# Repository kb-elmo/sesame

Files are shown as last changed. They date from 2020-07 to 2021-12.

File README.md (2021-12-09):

# Sesame

[][cc-by-nc-sa]
<a href="https://ko-fi.com/kb_elmo">kofibadge</a>

### Alice like ergo keyboard using only THT parts



### Partslist
 |Count|Part|Reference|LCSC Part #|
 |-|-|-|-|
 |1|ATmega32A 40 pin DIP (32L works too)|U1|C12703|
 |1|40 pin DIP socket (optional but highly recommended)|U1|C2332|
 |1|USB4085-GF-A USB Type-C socket|USB1|
 |1|500 mA polyfuse|F1|C207122|
 |2|6mm momentary push buttons|Boot,Reset|C620202|
 |1|16 MHz quartz crystal|XTAL1|C16212|
 |1|4.7 uF electrolytic capacitor|C1|C47879|
 |2|100 nF ceramic disk capacitor|C2,C3|C254092|
 |2|22 pF ceramic disk capacitor|C4,C5|C254096|
 |1|1.5 kΩ resistor|R1|C58620|
 |2|68 Ω resistor|R2,R3|C714279|
 |2|5.1 kΩ resistor|R4,R5|C714593|
 |1|10 kΩ resistor|R6|C119347|
 |2|3.6 V zener diode (DO-35 BZX55C3V6)|D1,D2|C2508|
 |66|universal switching diode (DO-35 1N4148)|D3-D68|C14516|
 
 The USB port can be found here:  
https://www.digikey.com/en/products/detail/gct/USB4085-GF-A/9859733

-----




This work is licensed under a
[Creative Commons Attribution-NonCommercial-ShareAlike 4.0 International License][cc-by-nc-sa].

[][cc-by-nc-sa]

[cc-by-nc-sa]: http://creativecommons.org/licenses/by-nc-sa/4.0/
[cc-by-nc-sa-image]: https://licensebuttons.net/l/by-nc-sa/4.0/88x31.png
[cc-by-nc-sa-shield]: https://img.shields.io/badge/License-CC%20BY--NC--SA%204.0-lightgrey.svg

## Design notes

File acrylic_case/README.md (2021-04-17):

# Sesame Acrylic Case

[][cc-by-nc-sa]

### Acrylic layer case for the Sesame Ergo



### To build the case you need:
|Count|Part|
|-|-|
|1|[Top plate](layer-top.dxf)|
|3|[Top frame](layer-frame-top.dxf)|
|1|[Switchplate](layer-plate.dxf)|
|2|[Bottom frame with USB cutout](layer-frame-bottom-usb.dxf)|
|2|[Bottom frame without USB cutout](layer-frame-bottom.dxf)|
|1|[Bottom plate](layer-bottom.dxf)|
|3|[Big feet plate](layer-feet-big.dxf)|
|2|[Small feet plate](layer-feet-small.dxf)|
|1|[Bottom feet plate](layer-feet-bottom.dxf)|

The case is designed to be built out of 2mm acrylic sheets with the switchplate in 1.5mm.  
For screwing everything together m2 standoffs and screws are used.

You can change the appearance of the board slightly by using more or less top frame plates.  
If you use 2 plates the keycaps will roughly sit at the same height of the case.  
With 3 plates the bottom of the keycaps sits slightly lower (which imho looks a bit better).  
The board in the picture has 2 top frame plates installed.

The case angle can be adjusted by the number of feet plates you attach to it.<br>
With six plates you will get roughly six degrees of typing angle.

---

This work is licensed under a
[Creative Commons Attribution-NonCommercial-ShareAlike 4.0 International License][cc-by-nc-sa].

[][cc-by-nc-sa]

[cc-by-nc-sa]: http://creativecommons.org/licenses/by-nc-sa/4.0/
[cc-by-nc-sa-image]: https://licensebuttons.net/l/by-nc-sa/4.0/88x31.png
[cc-by-nc-sa-shield]: https://img.shields.io/badge/License-CC%20BY--NC--SA%204.0-lightgrey.svg

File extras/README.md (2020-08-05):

# Extras for the Sesame







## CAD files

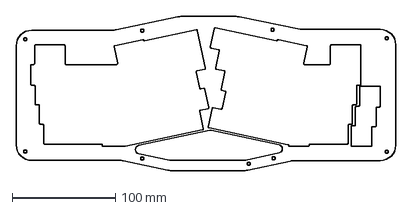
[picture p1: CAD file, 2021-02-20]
acrylic_case/layer-frame-top.dxf
368.4 x 149.6 mm

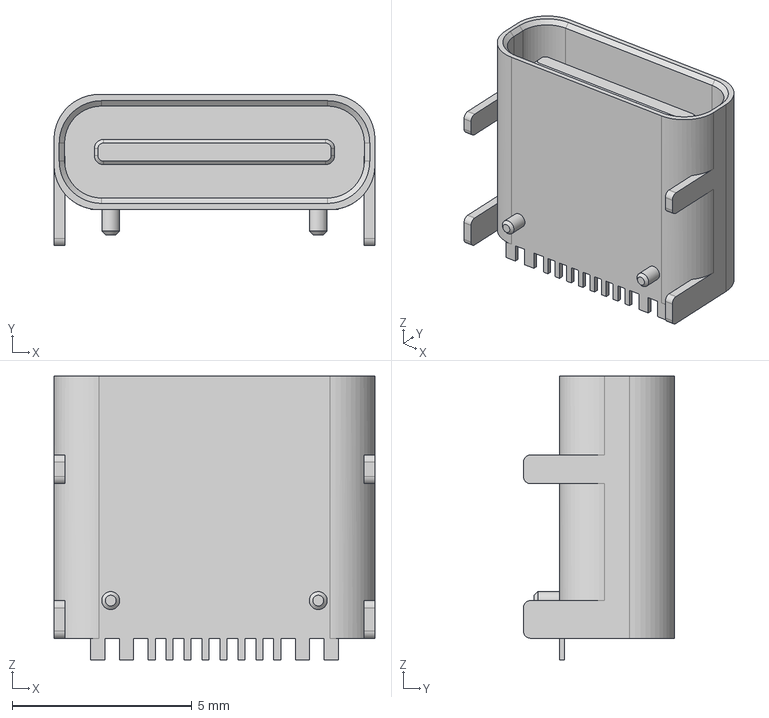
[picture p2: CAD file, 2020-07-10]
custom_parts/HRO TYPE-C-31-M-12.step
8.94 x 4.21 x 7.90 mm

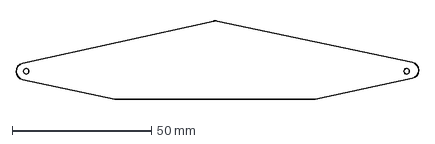
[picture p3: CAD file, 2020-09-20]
extras/case_parts/window.dxf
144.5 x 28.2 mm

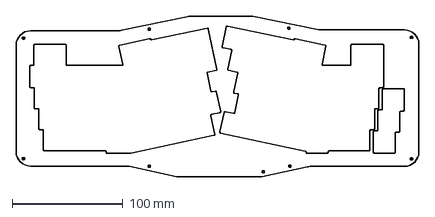
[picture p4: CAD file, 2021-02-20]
acrylic_case/layer-top.dxf
364.4 x 145.6 mm

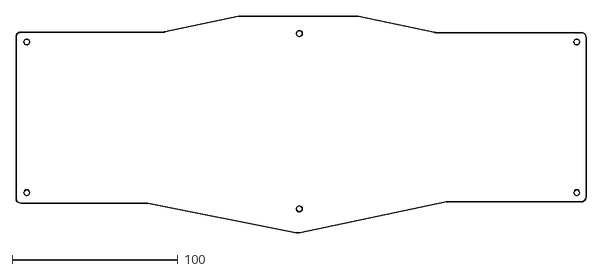
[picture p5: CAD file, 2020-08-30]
extras/case_parts/backplate-foam.dxf
344.4 x 131.0

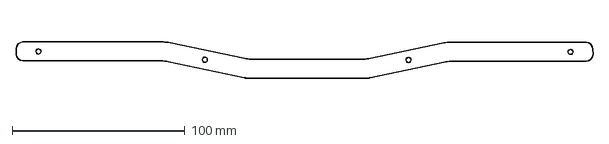
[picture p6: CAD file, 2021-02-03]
acrylic_case/layer-feet-small.dxf
334.3 x 20.9 mm

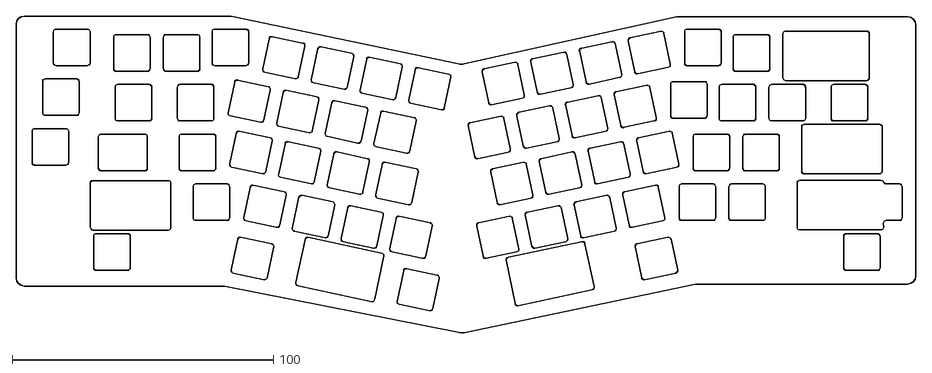
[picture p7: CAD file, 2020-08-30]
extras/case_parts/switchplate-foam.dxf
344.4 x 121.3

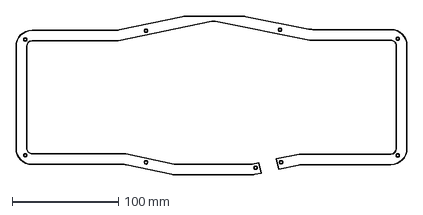
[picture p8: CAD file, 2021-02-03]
acrylic_case/layer-frame-bottom-usb.dxf
368.4 x 149.6 mm

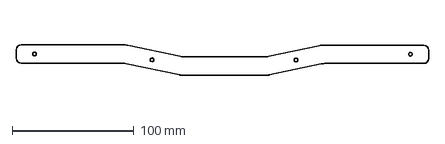
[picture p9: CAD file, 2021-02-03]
acrylic_case/layer-feet-big.dxf
338.3 x 24.9 mm

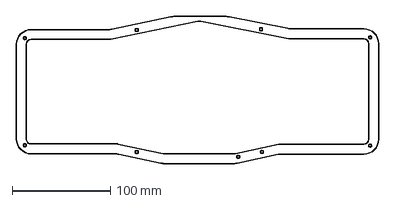
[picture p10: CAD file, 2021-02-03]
acrylic_case/layer-frame-bottom.dxf
368.4 x 149.6 mm

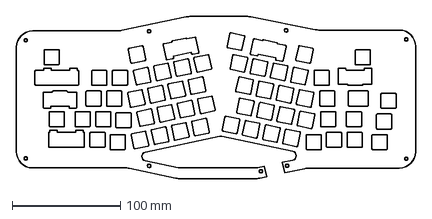
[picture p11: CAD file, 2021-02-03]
acrylic_case/layer-plate.dxf
368.4 x 149.6 mm

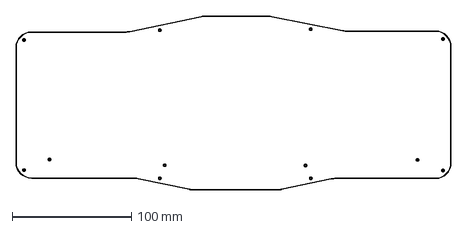
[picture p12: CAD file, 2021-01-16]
acrylic_case/layer-bottom.dxf
364.4 x 145.6 mm

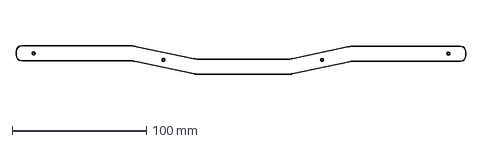
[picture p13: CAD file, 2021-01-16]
acrylic_case/layer-feet-bottom.dxf
334.3 x 20.9 mm

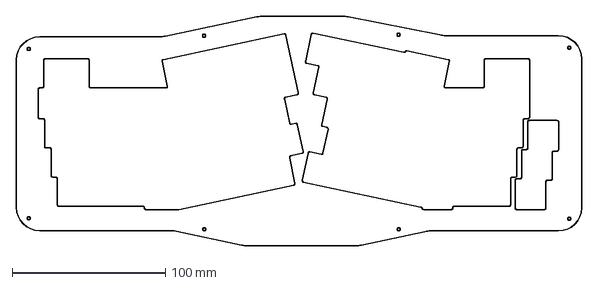
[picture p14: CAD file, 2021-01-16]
acrylic_case/sheet-top.dxf
368.4 x 149.6 mm

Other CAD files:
acrylic_case/sheet-frame-bottom-usb.dxf
acrylic_case/sheet-frame-bottom.dxf
acrylic_case/sheet-frame-top.dxf
acrylic_case/sheet-bottom.dxf

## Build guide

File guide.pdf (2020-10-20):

## Sesame Ergo build guide

Very quick and dirty build guide.
If you need further help DM me on Reddit (u/_vastrox_) or on Discord (elmo#0101).

Parts included:
1 | Sesame PCB
1 | Sesame Backplate (Logo on the back)
1 | Sesame FR4 switchplate
1 | Acrylic cover window
1 | Backplate foam
8 | M2 screws
8 | M2 nuts
6 | M2x4 standoffs for the backplate
2 | M2x10 standoffs for the acrylic window
1 | ATmega32A controller
1 | 40 pin DIP socket (optional but highly recommended)
1 | USB Type-C socket (USB4085-GF-A)
1 | 500 mA polyfuse
2 | 6mm momentary push buttons
1 | 16 MHz quartz crystal
1 | 4.7 uF electrolytic capacitor
2 | 100 nF ceramic disk capacitor
2 | 22 pF ceramic disk capacitor
1 | 10 kΩ resistor
1 | 1.5 kΩ resistor
2 | 68 Ω resistor
2 | 5.1 kΩ resistor
2 | 3.6 V zener diode (DO-35 BZX55C3V6)
80 | universal switching diode (DO-35 1N4148)

You only need 66 of the switching diodes for the board. The rest are replacements in case one gets damaged during soldering.

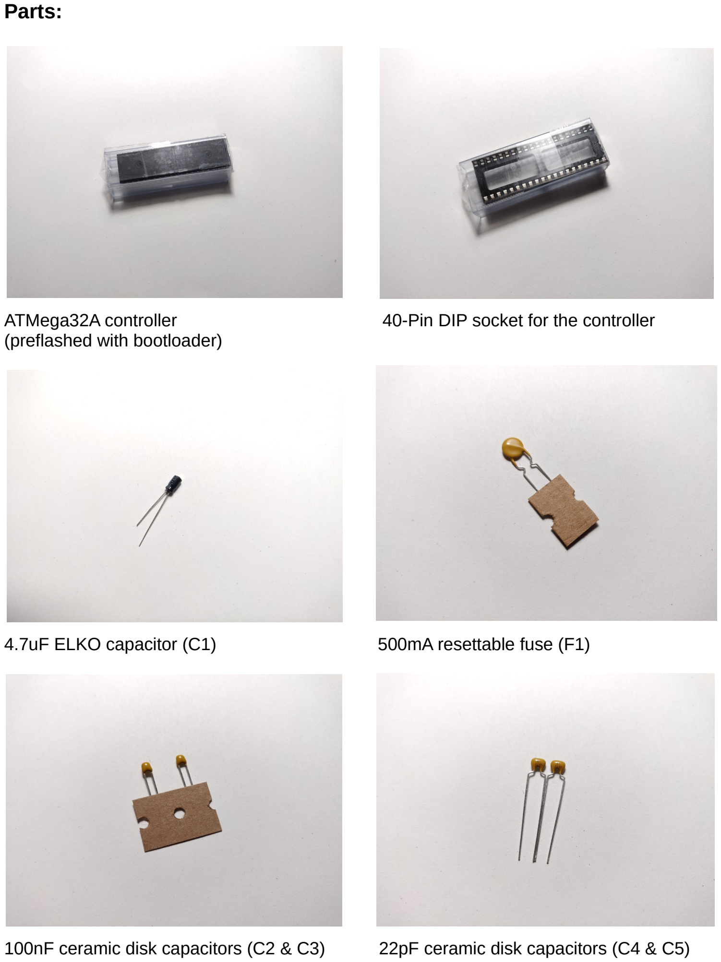
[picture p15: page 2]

Parts:

ATMega32A controller | 40-Pin DIP socket for the controller
(preflashed with bootloader)
4.7uF ELKO capacitor (C1) | 500mA resettable fuse (F1)
100nF ceramic disk capacitors (C2 & C3) | 22pF ceramic disk capacitors (C4 & C5)

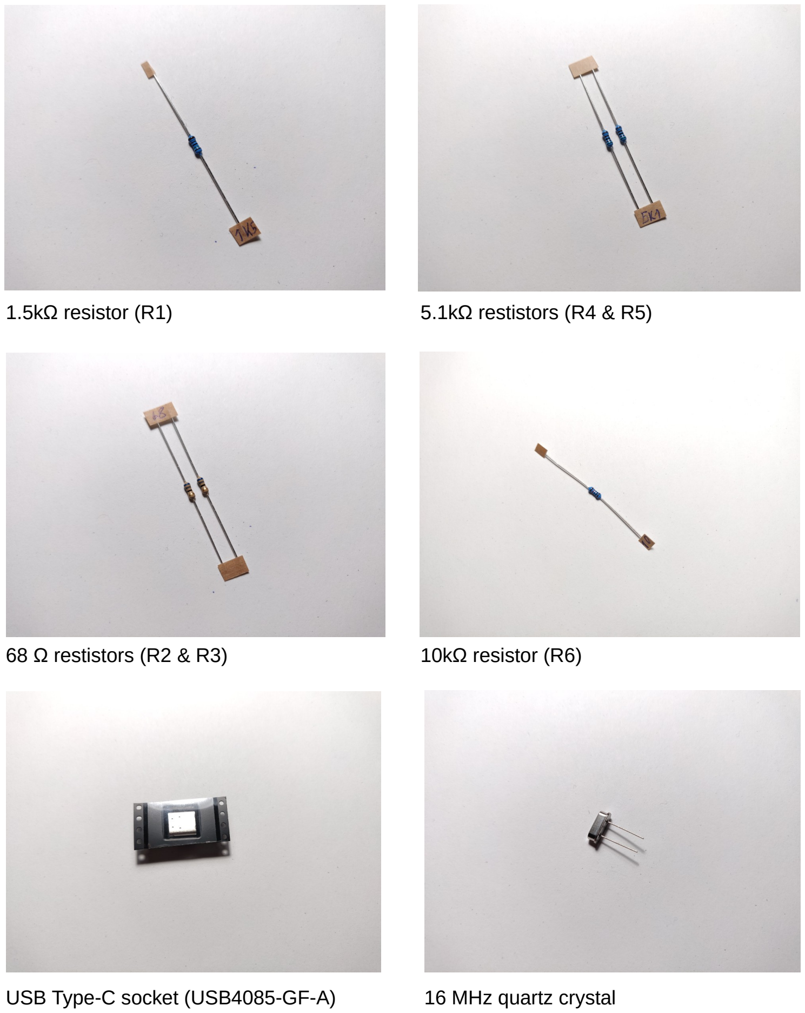
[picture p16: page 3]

1.5kΩ resistor (R1) | 5.1kΩ restistors (R4 & R5)
68 Ω restistors (R2 & R3) | 10kΩ resistor (R6)
USB Type-C socket (USB4085-GF-A) | 16 MHz quartz crystal

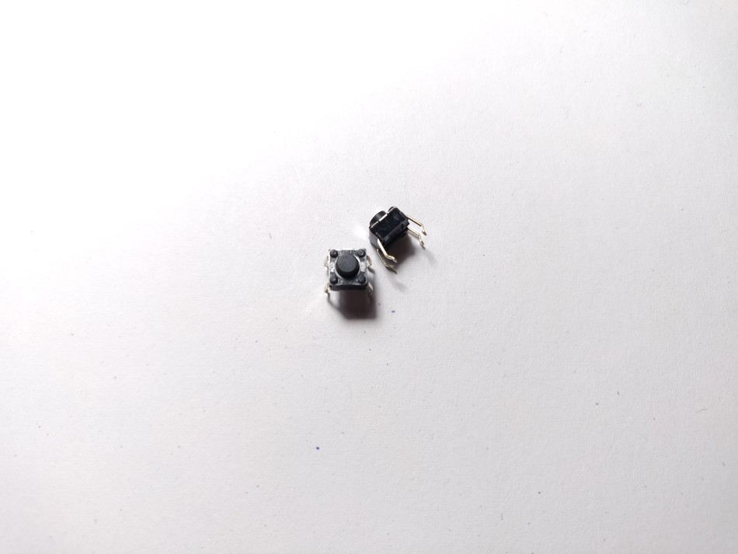
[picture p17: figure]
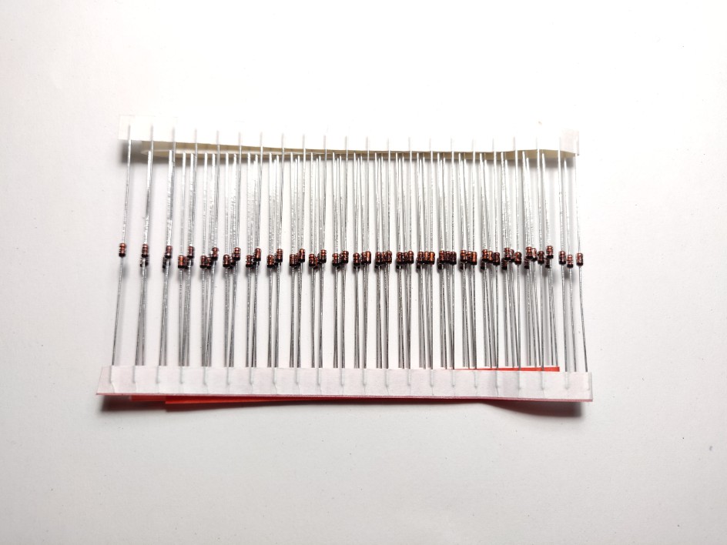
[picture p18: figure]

6mm pushbuttons (reset & boot) | universal switching diodes (80x)

Building the PCB:

1. Start with the USB-C port as this is the most complicated part to solder in this kit.
Put in the port and secure it in place with some electrical tape.
Next put on some flux over the pins on the bottom of the PCB.
Melt some solder on the tip of your iron and carefully drag the iron tip with the solder over the pins. The solder should stick to the pins without creating any bridges between them if you used enough flux.
If you don‘t get it right on the first try remove the solder with some whick and try it again. It‘s important that there are absolutely no shorts between the contacts. Otherwise the board will not work.
2. Next should be the controller socket. Put it in with the cutout nose like it‘s shown on the PCB silkscreen. Hold it in place with some electrical tape on top of the board. Solder every second pin on the board to prevent overheating the plastic. Then do the rest of the pins.
3. Solder in the quartz crystal into it‘s spot next to the controller (XTAL1). Polarity doesn‘t matter here. Do not pull hard on the parts legs as this can damage the part.

### 4. Solder in the capacitors. The values are as follows:

- C1 (ELKO! Watch the polarity! white side = negative) = 4.7uF
- C2 & C3 (next to the controller socket) = 100nF
- C4 & C5 (left and right of the crystal) = 22pF

### 5. Next up are the two 3.6V Zener diodes. They go into the spots D1 and D2. Watch the

polarity! The white line on the silkscreen has to match with the black or white line on the diode.
These are special diodes! They can not be exchanged with the standard switching diodes! Make sure that you are using the correct ones.
They are labeled 3V6 on their side. The switching diodes don‘t have that label.

### 6. Now come the resistors. Their values are as follows:

- R1 = 1.5kΩ
- R2 & R3 = 68Ω
- R4 & R5 = 5.1kΩ
- R6 (next to the buttons) = 10kΩ

### 7. Solder in the rest of the parts:

- the 500mA polyfuse (spot F1)
- the boot and reset pushbuttons
- the contacts labeled „AVR“ above the controller are left empty

### 8. Finish the board by soldering in all 66 diodes. Watch the polarity (white stripe)!

9. Lastly put the controller into the socket. Make sure that the indentation on the controller matches with the indentation in the socket! If you put it in the wrong way round it can destroy the controller.
Press it down firmly so that it sits flush with the socket. Take care to not bend any legs.

Assembly guide:

1. Start with the standoffs for the backplate.
Put in the standoffs (M2x4) from the bottom through the PCB and screw them in place with the M2 nuts.
2. Screw in the standoffs for the acrylic window.
Put the standoffs (M2x10) in from the front of the PCB and screw them in place with the M2 nuts on the back side.

### 3. Next put the included foam on the back of the PCB. The holes should align with the

standoffs. If it doesn‘t fit turn it around. It only fits on one way because the PCB is not perfectly symmetrical (even though it might look like it is).

4. Attach the backplate to the standoffs using the M2 screws.
(On this revision the topmost screw, the one below the controller, won‘t fit unfortunately due to a stupid change that I only made to the PCB and not to the backplate)
5. Screw on the acrylic window. Remove the protective foil on both sides first.

Building and flashing the bootloader:

If you bought the kit from me the controller is already flashed with the bootloader. You can skip this step!

Download the bootloader firmware from here: https://github.com/kb-elmo/sesame/tree/master/firmware/bootloader

You need either a Linux system or MingW on Windows for this as this requires compiling some stuff.

The firmware is already set up and you don‘t need to change anything in the configuration files for this board.

### 1. Build the bootloader firmware by running „make“ on your console

### 2. Make sure that you can reach the controller by executing a chip erase with

„avrude -c usbasp -p m32 -e“ (you have to run these commands as root in Linux)

### 3. Flash the firmware on the controller with „make flash“

### 4. Set the controller fuses to the correct values „make fuse“

### 5. Finally lock the controller bootloader in place with „make lock“

The avrdude tool should show a „success“ after each operation. If the flashing process was successful you can unplug the ASP flasher and plug in the USB now.

Building and flashing QMK:

The keyboard can be found on https://config.qmk.fm if you want to configure a static keymap or you can use VIA. I recommend the latter.

For VIA download the firmware for the board and the client from: https://caniusevia.com

Flash the firmware on the board using the QMK Toolbox which can be found here: https://github.com/qmk/qmk_toolbox/releases

To put the board into controller into bootloader mode press and hold down the boot button and tap the reset button once. Then let loose of the boot button.
The board should show up in your OS as a „USBasp“ device (or similar).
After the flashing process was successfull hit the reset button once to get into normal keyboard mode again.

You can of course also build the firmware yourself if you prefer that.
The code for this can be found in the QMK repository in keyboards/kb-elmo/sesame. I‘m not going into the details of this here

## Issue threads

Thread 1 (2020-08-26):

PCB gerbers aren't uploading properly to JLCPCB

evanronnei, 2020-08-26:
I'm not sure if this is an issue with the PCB, or an issue with JLC, but whenever I upload the gerbers for the PCB (using the zip file `/gerbers/sesame_20200810_190522.zip`) the preview image doesn't show up, and the dimensions are not filled in.

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

This issue does not happen with the switchplate and the backplate gerbers. I attempted to generate my own gerbers using [ai03's guide](https://wiki.ai03.com/books/pcb-design/page/pcb-guide-part-6---fill-zones-decoration-and-production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), but I get the same issue.

kb-elmo, 2020-08-30:
The gerbers in this repo are usually not very up to date and it is better if you just regenerate them fresh by yourself before you try to upload them anywhere.

I did update them now because I made some changes to the files anyways but I can't promise that they will stay up to date in the future.

Closed 2020-08-30.

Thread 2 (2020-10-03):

QMK won't compile via files

alif1994, 2020-10-03:
With EXTRAKEY_ENABLE set to yes. It will not compile as the error: "There are not enough available interfaces to support all functions."
Solved it by setting it to no in via's rules.mk

kb-elmo, 2020-10-03:
the VIA keymap is based on recent changes in the QMK master.

You will have to merge the QMK master in your fork and rerun "make git-submodule" to get the newest version of V-USB with the recent changes that enable the fourth HID endpoint in ATMEGA32 based boards which is a requirement for Extrakey to work

Closed 2020-10-03.

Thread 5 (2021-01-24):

acrylic case info

dayofdoom, 2021-01-24:
hello,

what width acrylic is suggested for the case layers?

thank you

kb-elmo, 2021-01-24:
added it to the case readme.

the case plates should be 2mm and the switchplate 1.5mm

Closed 2021-01-24.

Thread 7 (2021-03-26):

gerber to JLC PCB error

hanhanhan-kim, 2021-03-26:
Hello!
Thanks for designing this very cool keyboard! Looking at this this old issue [here](https://github.com/kb-elmo/sesame/issues/1) , I generated the gerbers myself, and this appears to work for me, except for the switchplate. The generated switchplate gerber fails to result in the correct output, when uploading to JLC PCB. Is there a fix?
Thanks!

kb-elmo, 2021-03-26:
The gerber viewer at JLCPCB can't process files with that many cutouts.

The files will work. They will just not display correctly in the gerber viewer.

Use 344.5 mm x 121.3 mm as the size for the switchplate PCB.

Closed 2021-03-26.

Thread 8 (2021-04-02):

R2 and R3 Silkscreen

dayofdoom, 2021-04-02:
Hello,

I believe the R2 and R3 silkscreen should be reversed, so that they are aligned numerically top to bottom. If this is intentional, please ignore this issue.

Thank you

kb-elmo, 2021-04-03:
I appreciate the effort

but no.

this ain't the case lol

Closed 2021-04-03.

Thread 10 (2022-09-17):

Huge fan of the PCB, could it support ai03 daughter board?

coadotvn, 2022-09-17:
I'm trying to create a CNC aluminum case for this board. Is there any chance to have usb daughter board supported?

I didn't have much knowledge about PCB designing to edit it by myself, but I will try my best to design a well-made case for it 🙏

kb-elmo, 2022-09-17:
Hi there.

It is definitely technically possible to put a daughterboard connector on this PCB.
However it would not make much sense in my personal opinion.

The entire idea behind this board was to create an easy DIY version of the Alice.
As such it intentionally only used THT soldering components to make assembly easier for inexperienced users.
Putting a daugtherboard on it would require adding SMD components which kinda defeats that purpose.

It would also not make much sense from the overall design philosophy that this board is made after.
Given that this is a stacked FR4 board a daughterboard wouldn't really have any place to go.
Sure if you were going to make a case for it that would change but the entire PCB wasn't really designed for being mounted in a case anyways. The entire outline would make a real case look quite bulky due to the wide overhangs on each side.

And besides that this project as a whole is kinda seen as "completed" from my side.
Meaning I'm not planning to do any major changes to it anymore at this point.

But nothing is stopping you from downloading the files and modifying them in KiCAD.
Adding a new connector is quite easy and there's lots of tutorials for KiCAD on Youtube 😄

coadotvn, 2022-09-17:
Thank you for fast response. Everything seem reasonable now. I will try to change the port direction a bit for the first prototype, hope everything goes well 🙏

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

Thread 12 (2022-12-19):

Can i Replace Parts

K-20, 2022-12-19:
https://www.lcsc.com/product-detail/Ceramic-Disc-Capacitors_Dersonic-CC1H104ZC1FD3F5O10MF_C254092.html
https://www.lcsc.com/product-detail/Ceramic-Disc-Capacitors_Dersonic-CC1H220JA1FDCH4B10MF_C254096.html
https://www.lcsc.com/product-detail/Through-Hole-Resistors_Huaxing-Mechanical-Elec-MF1-2WS-5-1K-1-T52_C714593.html
https://www.lcsc.com/product-detail/Zener-Diodes_ST-Semtech-BZX55C3V6_C2508.html

i misssing 4 parts !!! and Can i Replace it !!

Thank you !

Closed 2024-09-10.

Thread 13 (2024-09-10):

Usb device not recognized

M13G, 2024-09-10:
Hey kb-elmo
I recently redesigned USB C port on Sesame PCB and flashed the ATMEGA32A successfully by using your guide but when I'm trying to connect the PCB to my computer I get this error (USB device not recognized)
I was wondering if you could help me with that
[sesame.zip](https://github.com/user-attachments/files/16946870/sesame.zip)
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

kb-elmo, 2024-09-10:
Without a schematic of the electronics I can't tell if there is something wrong.

This isn't really the right place to ask for help with your own redesigns or forks of this board though.
If you need help with doing changes to a PCB design on your own the Keyboard Atelier Discord would be the better place to ask for help.

https://discord.gg/b7vwhHS

Closed 2024-09-10.

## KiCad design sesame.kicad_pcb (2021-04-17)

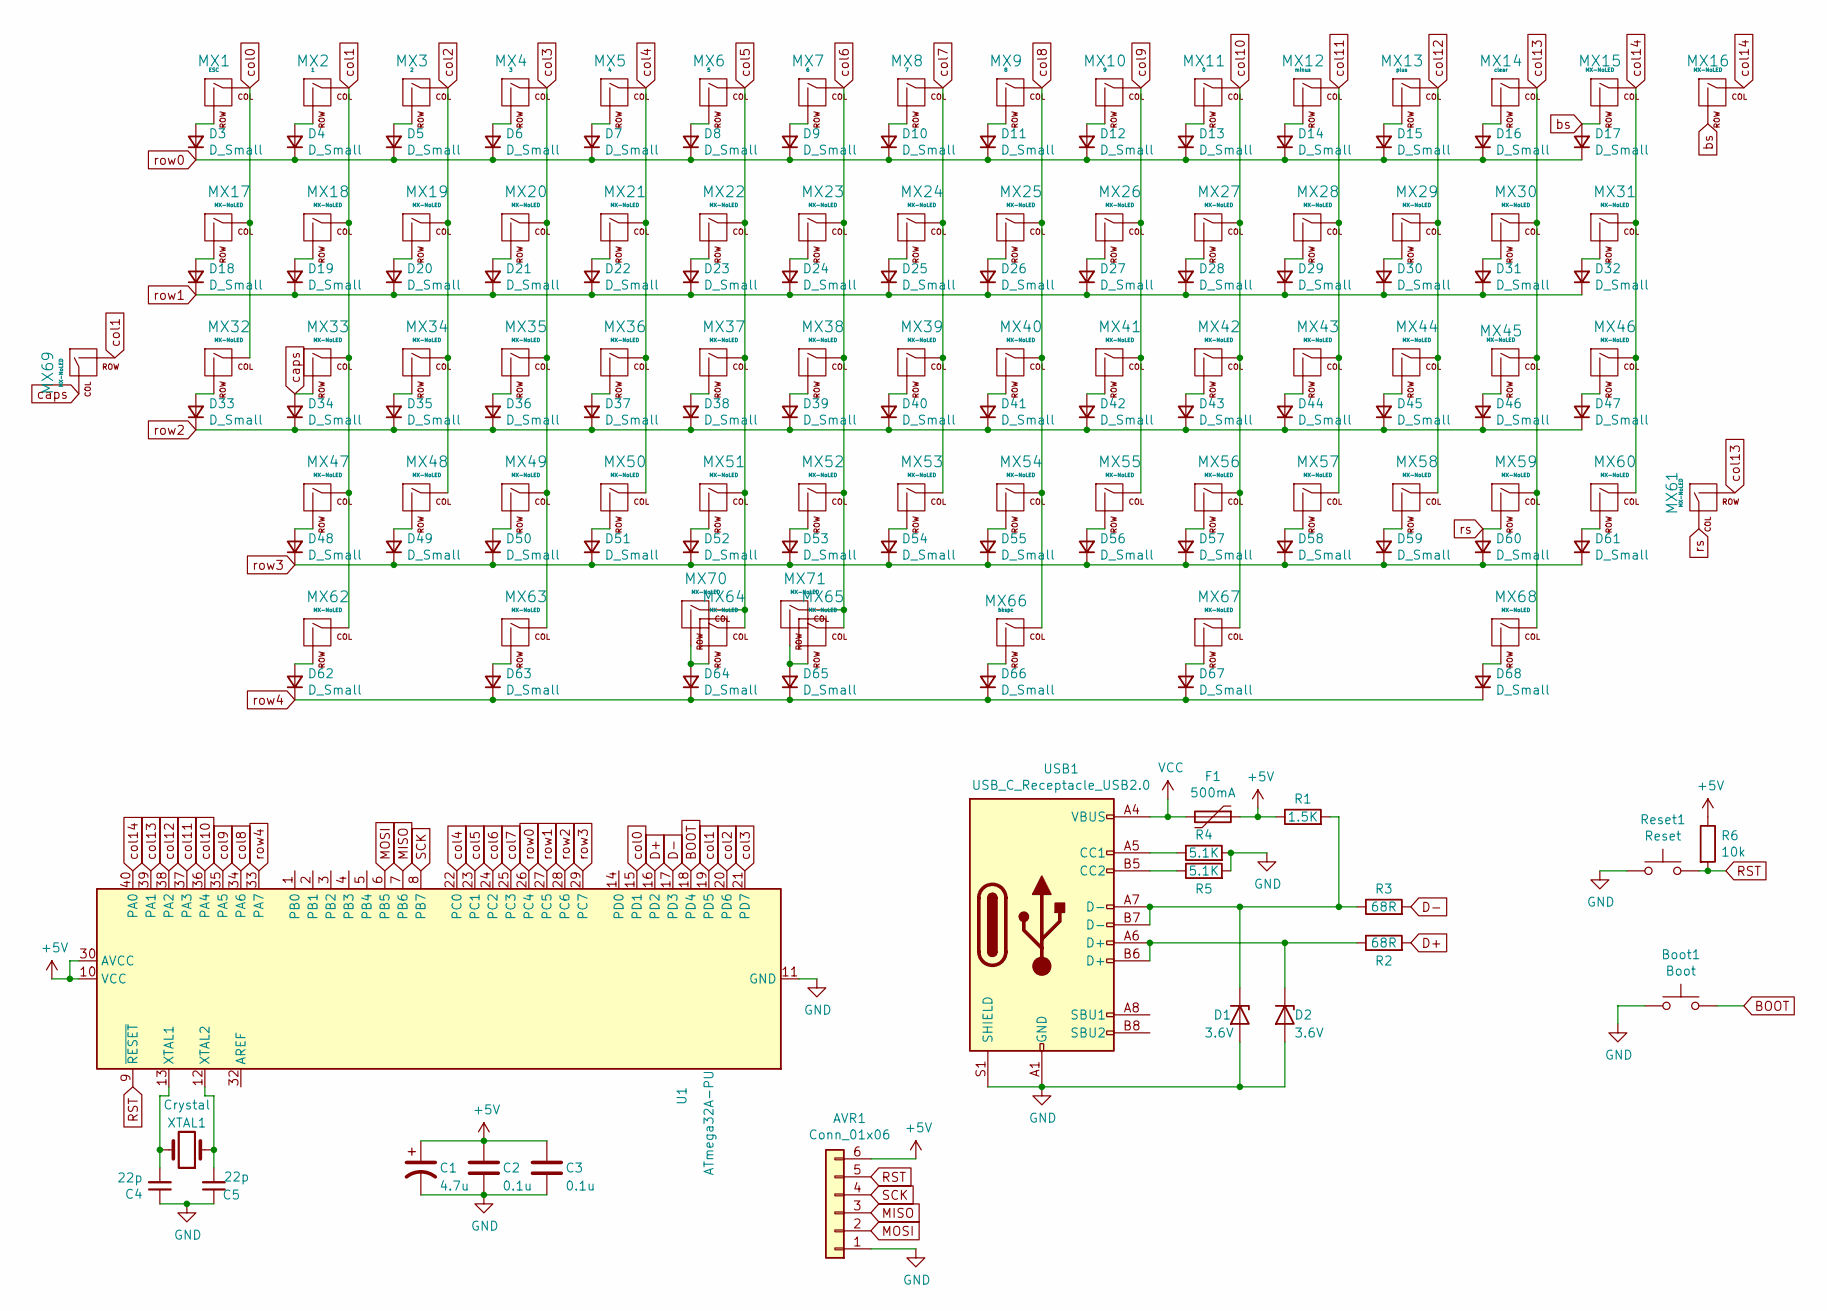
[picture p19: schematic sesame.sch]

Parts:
AVR1: Conn_01x06; PinHeader_1x06_P2.54mm_Vertical
Boot1: Boot; SW_PUSH_6mm
C1: 4.7u; CP_Radial_D4.0mm_P1.50mm
C2, C3: 0.1u; C_Disc_D5.0mm_W2.5mm_P5.00mm
C4, C5: 22p; C_Disc_D5.0mm_W2.5mm_P2.50mm
D1, D2: 3.6V; D_DO-35_SOD27_P7.62mm_Horizontal
D3, D4, D5, D6, D7, D8, D9, D10, D11, D12, D13, D14, D15, D16, D17, D18, D19, D20, D21, D22, D23, D24, D25, D26, D27, D28, D29, D30, D31, D32, D33, D34, D35, D36, D37, D38, D39, D40, D41, D42, D43, D44, D45, D46, D47, D48, D49, D50, D51, D52, D53, D54, D55, D56, D57, D58, D59, D60, D61, D62, D63, D64, D65, D66, D67, D68: D_Small; D_DO-35_SOD27_P7.62mm_Horizontal
F1: 500mA; Fuse_Littelfuse_395Series
MX1: ESC; MXOnly-1U-NoLED
MX2: 1; MXOnly-1U-NoLED
MX3: 2; MXOnly-1U-NoLED
MX4: 3; MXOnly-1U-NoLED
MX5: 4; MXOnly-1U-NoLED
MX6: 5; MXOnly-1U-NoLED
MX7: 6; MXOnly-1U-NoLED
MX8: 7; MXOnly-1U-NoLED
MX9: 8; MXOnly-1U-NoLED
MX10: 9; MXOnly-1U-NoLED
MX11: 0; MXOnly-1U-NoLED
MX12: minus; MXOnly-1U-NoLED
MX13: plus; MXOnly-1U-NoLED
MX14: clear; MXOnly-1U-NoLED
MX15: MX-NoLED; MXOnly-2U-NoLED
MX16, MX17, MX19, MX20, MX21, MX22, MX23, MX24, MX25, MX26, MX27, MX28, MX29, MX30, MX32, MX34, MX35, MX36, MX37, MX38, MX39, MX40, MX41, MX42, MX43, MX44, MX45, MX48, MX49, MX50, MX51, MX52, MX53, MX54, MX55, MX56, MX57, MX58, MX60, MX67, MX68, MX71: MX-NoLED; MXOnly-1U-NoLED
MX18, MX31, MX62, MX63: MX-NoLED; MXOnly-1.5U-NoLED
MX33, MX59: MX-NoLED; MXOnly-1.75U-NoLED
MX46, MX70: MX-NoLED; MXOnly-2.25U-ReversedStabilizers-NoLED
MX47: MX-NoLED; MXOnly-2.25U-NoLED
MX61: MX-NoLED; MXOnly-2.75U-NoLED
MX64: MX-NoLED; MXOnly-2U-ReversedStabilizers-NoLED
MX65, MX69: MX-NoLED; MXOnly-1.25U-NoLED
MX66: bkspc; MXOnly-2.25U-ReversedStabilizers-NoLED
R1: 1.5K; R_Axial_DIN0207_L6.3mm_D2.5mm_P10.16mm_Horizontal
R2, R3: 68R; R_Axial_DIN0207_L6.3mm_D2.5mm_P10.16mm_Horizontal
R4, R5: 5.1K; R_Axial_DIN0207_L6.3mm_D2.5mm_P10.16mm_Horizontal
R6: 10k; R_Axial_DIN0207_L6.3mm_D2.5mm_P10.16mm_Horizontal
Reset1: Reset; SW_PUSH_6mm
U1: ATmega32A-PU; DIP-40_W15.24mm
USB1: USB_C_Receptacle_USB2.0; USB_C_GCT_USB4085
XTAL1: Crystal; Crystal_HC49-4H_Vertical

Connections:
+5V: AVR1.6, C1.1, C2.1, C3.1, F1.1, R1.1, R6.1, U1.10 (VCC), U1.30 (AVCC)
BOOT: Boot1.2, U1.18 (PD4); also elsewhere on the board
D+: R2.2, U1.16 (PD2)
D-: R3.2, U1.17 (PD3)
GND: AVR1.1, Boot1.1, C1.2, C2.2, C3.2, C4.1, C5.1, D1.2 (A), D2.2 (A), R4.2, R5.2, Reset1.1, U1.11 (GND), U1.31 (GND), USB1.A1 (GND), USB1.A12 (GND), USB1.B1 (GND), USB1.B12 (GND), USB1.S1 (SHIELD); also elsewhere on the board
MISO: AVR1.3, U1.7 (PB6)
MOSI: AVR1.2, U1.6 (PB5)
unnamed: C4.2, U1.13 (XTAL1), XTAL1.2
unnamed: C5.2, U1.12 (XTAL2), XTAL1.1
unnamed: D1.1 (K), R1.2, R3.1, USB1.A7 (D-), USB1.B7 (D-)
unnamed: D2.1 (K), R2.1, USB1.A6 (D+), USB1.B6 (D+)
unnamed: D3.2 (A), MX1.2 (ROW)
unnamed: D4.2 (A), MX2.2 (ROW)
unnamed: D5.2 (A), MX3.2 (ROW)
unnamed: D6.2 (A), MX4.2 (ROW)
unnamed: D7.2 (A), MX5.2 (ROW)
unnamed: D8.2 (A), MX6.2 (ROW)
unnamed: D9.2 (A), MX7.2 (ROW)
unnamed: D10.2 (A), MX8.2 (ROW)
unnamed: D11.2 (A), MX9.2 (ROW)
unnamed: D12.2 (A), MX10.2 (ROW)
unnamed: D13.2 (A), MX11.2 (ROW)
unnamed: D14.2 (A), MX12.2 (ROW)
unnamed: D15.2 (A), MX13.2 (ROW)
unnamed: D16.2 (A), MX14.2 (ROW)
unnamed: D18.2 (A), MX17.2 (ROW)
unnamed: D19.2 (A), MX18.2 (ROW)
unnamed: D20.2 (A), MX19.2 (ROW)
unnamed: D21.2 (A), MX20.2 (ROW)
unnamed: D22.2 (A), MX21.2 (ROW)
unnamed: D23.2 (A), MX22.2 (ROW)
unnamed: D24.2 (A), MX23.2 (ROW)
unnamed: D25.2 (A), MX24.2 (ROW)
unnamed: D26.2 (A), MX25.2 (ROW)
unnamed: D27.2 (A), MX26.2 (ROW)
unnamed: D28.2 (A), MX27.2 (ROW)
unnamed: D29.2 (A), MX28.2 (ROW)
unnamed: D30.2 (A), MX29.2 (ROW)
unnamed: D31.2 (A), MX30.2 (ROW)
unnamed: D32.2 (A), MX31.2 (ROW)
unnamed: D33.2 (A), MX32.2 (ROW)
unnamed: D35.2 (A), MX34.2 (ROW)
unnamed: D36.2 (A), MX35.2 (ROW)
unnamed: D37.2 (A), MX36.2 (ROW)
unnamed: D38.2 (A), MX37.2 (ROW)
unnamed: D39.2 (A), MX38.2 (ROW)
unnamed: D40.2 (A), MX39.2 (ROW)
unnamed: D41.2 (A), MX40.2 (ROW)
unnamed: D42.2 (A), MX41.2 (ROW)
unnamed: D43.2 (A), MX42.2 (ROW)
unnamed: D44.2 (A), MX43.2 (ROW)
unnamed: D45.2 (A), MX44.2 (ROW)
unnamed: D46.2 (A), MX45.2 (ROW)
unnamed: D47.2 (A), MX46.2 (ROW)
unnamed: D48.2 (A), MX47.2 (ROW)
unnamed: D49.2 (A), MX48.2 (ROW)
unnamed: D50.2 (A), MX49.2 (ROW)
unnamed: D51.2 (A), MX50.2 (ROW)
unnamed: D52.2 (A), MX51.2 (ROW)
unnamed: D53.2 (A), MX52.2 (ROW)
unnamed: D54.2 (A), MX53.2 (ROW)
unnamed: D55.2 (A), MX54.2 (ROW)
unnamed: D56.2 (A), MX55.2 (ROW)
unnamed: D57.2 (A), MX56.2 (ROW)
unnamed: D58.2 (A), MX57.2 (ROW)
unnamed: D59.2 (A), MX58.2 (ROW)
unnamed: D61.2 (A), MX60.2 (ROW)
unnamed: D62.2 (A), MX62.2 (ROW)
unnamed: D63.2 (A), MX63.2 (ROW)
unnamed: D64.2 (A), MX64.2 (ROW), MX70.2 (ROW)
unnamed: D65.2 (A), MX65.2 (ROW), MX71.2 (ROW)
unnamed: D66.2 (A), MX66.2 (ROW)
unnamed: D67.2 (A), MX67.2 (ROW)
unnamed: D68.2 (A), MX68.2 (ROW)
unnamed: R4.1, USB1.A5 (CC1)
unnamed: R5.1, USB1.B5 (CC2)
RST: AVR1.5, R6.2, Reset1.2, U1.9 (~RESET); also elsewhere on the board
SCK: AVR1.4, U1.8 (PB7)
VCC: F1.2, USB1.A4 (VBUS), USB1.A9 (VBUS), USB1.B4 (VBUS), USB1.B9 (VBUS)
bs: D17.2 (A), MX15.2 (ROW), MX16.2 (ROW)
caps: D34.2 (A), MX33.2 (ROW), MX69.1 (COL)
col0: MX1.1 (COL), MX17.1 (COL), MX32.1 (COL), U1.15 (PD1)
col1: MX2.1 (COL), MX18.1 (COL), MX33.1 (COL), MX47.1 (COL), MX62.1 (COL), MX69.2 (ROW), U1.19 (PD5)
col2: MX3.1 (COL), MX19.1 (COL), MX34.1 (COL), MX48.1 (COL), U1.20 (PD6)
col3: MX4.1 (COL), MX20.1 (COL), MX35.1 (COL), MX49.1 (COL), MX63.1 (COL), U1.21 (PD7)
col4: MX5.1 (COL), MX21.1 (COL), MX36.1 (COL), MX50.1 (COL), U1.22 (PC0)
col5: MX6.1 (COL), MX22.1 (COL), MX37.1 (COL), MX51.1 (COL), MX64.1 (COL), MX70.1 (COL), U1.23 (PC1)
col6: MX7.1 (COL), MX23.1 (COL), MX38.1 (COL), MX52.1 (COL), MX65.1 (COL), MX71.1 (COL), U1.24 (PC2)
col7: MX8.1 (COL), MX24.1 (COL), MX39.1 (COL), MX53.1 (COL), U1.25 (PC3)
col8: MX9.1 (COL), MX25.1 (COL), MX40.1 (COL), MX54.1 (COL), MX66.1 (COL), U1.34 (PA6)
col9: MX10.1 (COL), MX26.1 (COL), MX41.1 (COL), MX55.1 (COL), U1.35 (PA5)
col10: MX11.1 (COL), MX27.1 (COL), MX42.1 (COL), MX56.1 (COL), MX67.1 (COL), U1.36 (PA4)
col11: MX12.1 (COL), MX28.1 (COL), MX43.1 (COL), MX57.1 (COL), U1.37 (PA3)
col12: MX13.1 (COL), MX29.1 (COL), MX44.1 (COL), MX58.1 (COL), U1.38 (PA2)
col13: MX14.1 (COL), MX30.1 (COL), MX45.1 (COL), MX59.1 (COL), MX61.2 (ROW), MX68.1 (COL), U1.39 (PA1)
col14: MX15.1 (COL), MX16.1 (COL), MX31.1 (COL), MX46.1 (COL), MX60.1 (COL), U1.40 (PA0)
row0: D3.1 (K), D4.1 (K), D5.1 (K), D6.1 (K), D7.1 (K), D8.1 (K), D9.1 (K), D10.1 (K), D11.1 (K), D12.1 (K), D13.1 (K), D14.1 (K), D15.1 (K), D16.1 (K), D17.1 (K), U1.26 (PC4)
row1: D18.1 (K), D19.1 (K), D20.1 (K), D21.1 (K), D22.1 (K), D23.1 (K), D24.1 (K), D25.1 (K), D26.1 (K), D27.1 (K), D28.1 (K), D29.1 (K), D30.1 (K), D31.1 (K), D32.1 (K), U1.27 (PC5)
row2: D33.1 (K), D34.1 (K), D35.1 (K), D36.1 (K), D37.1 (K), D38.1 (K), D39.1 (K), D40.1 (K), D41.1 (K), D42.1 (K), D43.1 (K), D44.1 (K), D45.1 (K), D46.1 (K), D47.1 (K), U1.28 (PC6)
row3: D48.1 (K), D49.1 (K), D50.1 (K), D51.1 (K), D52.1 (K), D53.1 (K), D54.1 (K), D55.1 (K), D56.1 (K), D57.1 (K), D58.1 (K), D59.1 (K), D60.1 (K), D61.1 (K), U1.29 (PC7)
row4: D62.1 (K), D63.1 (K), D64.1 (K), D65.1 (K), D66.1 (K), D67.1 (K), D68.1 (K), U1.33 (PA7)
rs: D60.2 (A), MX59.2 (ROW), MX61.1 (COL)

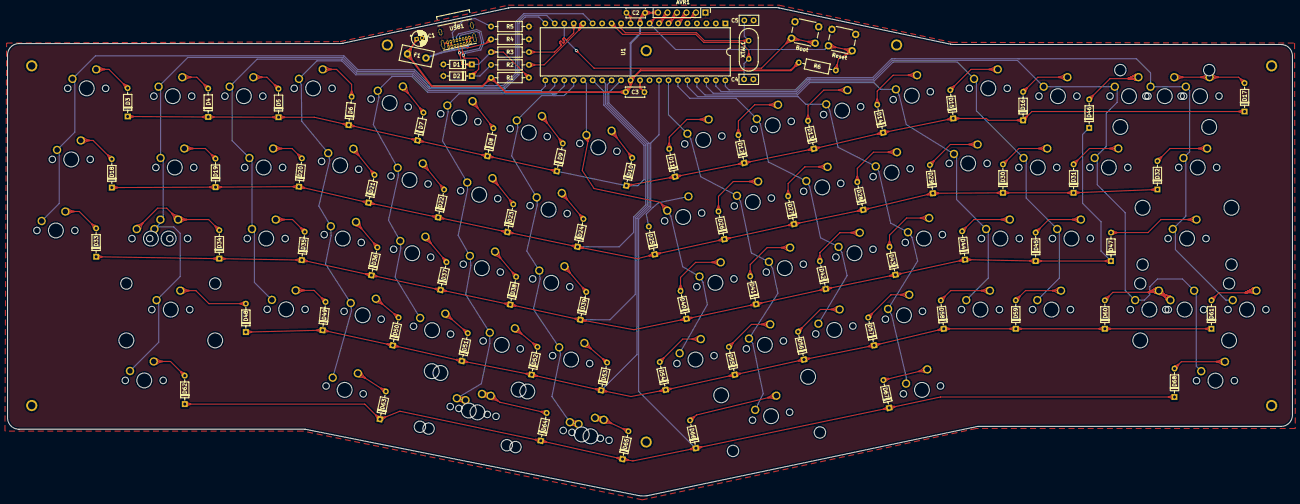
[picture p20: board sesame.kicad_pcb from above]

Board: 2 copper layers, 344.4 x 130.9 mm, 157 parts (0 on the bottom side), 102 nets.

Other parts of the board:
Boot: Boot; SW_PUSH_6mm
Reset: Reset; SW_PUSH_6mm

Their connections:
BOOT: Boot.2; also elsewhere on the board
GND: Boot.1, Reset.1; also elsewhere on the board
RST: Reset.2; also elsewhere on the board

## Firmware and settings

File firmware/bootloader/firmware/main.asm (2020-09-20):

main.elf:     file format elf32-avr

SYMBOL TABLE:
00007000 l    d  .text	00000000 .text
00800060 l    d  .data	00000000 .data
00800066 l    d  .bss	00000000 .bss
0080009b l    d  .noinit	00000000 .noinit
00000000 l    d  .comment	00000000 .comment
00000000 l    d  .note.gnu.avr.deviceinfo	00000000 .note.gnu.avr.deviceinfo
00000000 l    d  .debug_aranges	00000000 .debug_aranges
00000000 l    d  .debug_info	00000000 .debug_info
00000000 l    d  .debug_abbrev	00000000 .debug_abbrev
00000000 l    d  .debug_line	00000000 .debug_line
00000000 l    d  .debug_frame	00000000 .debug_frame
00000000 l    d  .debug_str	00000000 .debug_str
00000000 l    d  .debug_loc	00000000 .debug_loc
00000000 l    d  .debug_ranges	00000000 .debug_ranges
00000000 l    d  .debug_macro	00000000 .debug_macro
00000000 l    df *ABS*	00000000 main.c
0000003e l       *ABS*	00000000 __SP_H__
0000003d l       *ABS*	00000000 __SP_L__
0000003f l       *ABS*	00000000 __SREG__
00000000 l       *ABS*	00000000 __tmp_reg__
00000001 l       *ABS*	00000000 __zero_reg__
000070e0 l       .text	00000000 __BOOTLOADERENTRY_FROMSOFTWARE__bootup_investigate_RAMEND_done6
000070de l       .text	00000000 __BOOTLOADERENTRY_FROMSOFTWARE__bootup_investigate_RAMEND_mismatch6
0080009c l     O .noinit	00000001 __BOOTLOADERENTRY_FROMSOFTWARE__bootup_RAMEND_doesmatch
0080009b l     O .noinit	00000001 __BOOTLOADERENTRY_FROMSOFTWARE__bootup_MCUCSR
00800062 l     O .data	00000004 signatureBytes
0080006f l     O .bss	00000001 stayinloader
0000741e l       .text	00000000 _mywait_sleeploop227
0000747c l       .text	00000000 _mywait_sleeploop350
00800070 l     O .bss	00000001 usbMsgFlags
00800066 l     O .bss	00000004 replyBuffer.2209
0080006d l     O .bss	00000002 currentAddress
0080006c l     O .bss	00000001 bytesRemaining
0080006b l     O .bss	00000001 isLastPage
0080006a l     O .bss	00000001 currentRequest
00800060 l     O .data	00000001 usbMsgLen
00000000 l    df *ABS*	00000000 _clear_bss.o
00007108 l       .text	00000000 .do_clear_bss_start
00007106 l       .text	00000000 .do_clear_bss_loop
00000000 l    df *ABS*	00000000 usbdrv/usbdrvasm.o
00007138 l       .text	00000000 usbCrcLoopEntry
00007126 l       .text	00000000 usbCrcByteLoop
0000712a l       .text	00000000 usbCrcBitLoop
00007134 l       .text	00000000 usbCrcNoXor
0000713c l       .text	00000000 usbCrcReady
0000714e l       .text	00000000 waitForJ
00007154 l       .text	00000000 waitForK
0000716e l       .text	00000000 foundK
00007280 l       .text	00000000 sofError
00007188 l       .text	00000000 haveTwoBitsK
00007216 l       .text	00000000 rxbit1
000071a4 l       .text	00000000 unstuff6
000071ec l       .text	00000000 didUnstuff6
000071b0 l       .text	00000000 unstuff7
000071fa l       .text	00000000 didUnstuff7
000071bc l       .text	00000000 unstuffEven
0000723a l       .text	00000000 se0
00007212 l       .text	00000000 didUnstuffE
000071cc l       .text	00000000 unstuffOdd
00007226 l       .text	00000000 didUnstuffO
000071dc l       .text	00000000 rxByteLoop
000071e8 l       .text	00000000 skipLeap
00007202 l       .text	00000000 rxBitLoop
00007232 l       .text	00000000 overflow
00007236 l       .text	00000000 ignorePacket
00007268 l       .text	00000000 storeTokenAndReturn
0000728a l       .text	00000000 handleData
000072b4 l       .text	00000000 handleIn
00007268 l       .text	00000000 handleSetupOrOut
0000726c l       .text	00000000 doReturn
000072e8 l       .text	00000000 sendNakAndReti
000072ec l       .text	00000000 sendAckAndReti
000072ee l       .text	00000000 sendCntAndReti
000072f6 l       .text	00000000 usbSendAndReti
000072d0 l       .text	00000000 bitstuffN
00007310 l       .text	00000000 didStuffN
000072dc l       .text	00000000 bitstuff6
0000731e l       .text	00000000 didStuff6
000072e4 l       .text	00000000 bitstuff7
0000732a l       .text	00000000 didStuff7
000072f0 l       .text	00000000 sendX3AndReti
00007304 l       .text	00000000 txByteLoop
00007306 l       .text	00000000 txBitLoop
00007352 l       .text	00000000 skipAddrAssign
00007362 l       .text	00000000 se0Delay
00000000 l    df *ABS*	00000000 _exit.o
00007856 l       .text	00000000 __stop_program
00007084 g     O .text	00000012 usbDescriptorDevice
0000783c g       .text	00000000 eeprom_write_r18
00007146 g     F .text	00000000 __vector_1
00800071 g     O .bss	0000000b usbTxBuf
00000000 g       *ABS*	00000000 nullVector
0000ffa0 g       *ABS*	00000000 __DATA_REGION_LENGTH__
00007072 g       .text	00000000 __trampolines_start
00007858 g       .text	00000000 _etext
000070c0 g     O .text	00000004 usbDescriptorString0
00007112  w      .text	00000000 __vector_12
00007112 g       .text	00000000 __bad_interrupt
0000785e g       *ABS*	00000000 __data_load_end
00007112  w      .text	00000000 __vector_6
00007114 g       .text	00000000 usbCrc16
00007072 g       .text	00000000 __trampolines_end
00007112  w      .text	00000000 __vector_3
000070d0 g     F .text	00000018 __BOOTLOADERENTRY_FROMSOFTWARE__bootup_investigate_RAMEND
00007858 g       *ABS*	00000000 __data_load_start
000070c4 g       .text	00000000 __dtors_end
0080009b g       .bss	00000000 __bss_end
00000400 g       *ABS*	00000000 __LOCK_REGION_LENGTH__
00007054 g     O .text	0000001e bootloader__do_spm
0000783a g     F .text	0000001a eeprom_write_byte
00007112  w      .text	00000000 __vector_11
000070c4  w      .text	00000000 __init
00007112  w      .text	00000000 __vector_13
0000713e g       .text	00000000 usbCrc16Append
00007112  w      .text	00000000 __vector_17
00007112  w      .text	00000000 __vector_19
00007112  w      .text	00000000 __vector_7
00007072 g     O .text	00000012 usbDescriptorConfiguration
000070fe g       .text	00000010 .hidden __do_clear_bss
0080007c g     O .bss	00000001 usbDeviceAddr
00810000 g       .comment	00000000 __eeprom_end
0080007d g     O .bss	00000001 usbRxToken
00007000 g       .text	00000000 __vectors
0000782a g     F .text	00000010 eeprom_read_byte
00800066 g       .data	00000000 __data_end
000070a4 g     O .text	0000001c usbDescriptorStringVendor
0080007e g     O .bss	00000001 usbInputBufOffset
00007000  w      .text	00000000 __vector_default
00007112  w      .text	00000000 __vector_5
00000400 g       *ABS*	00000000 __SIGNATURE_REGION_LENGTH__
000070c4 g       .text	00000000 __ctors_start
000070e8 g       .text	00000016 .hidden __do_copy_data
0000736e g     F .text	0000009e usbFunctionSetup_USBASP_FUNC_TRANSMIT
00800066 g       .bss	00000000 __bss_start
0000740c g     F .text	0000041e main
00007112  w      .text	00000000 __vector_4
00800061 g     O .data	00000001 usbTxLen
00000000  w      *ABS*	00000000 __heap_end
00007112  w      .text	00000000 __vector_9
00007112  w      .text	00000000 __vector_2
00000400 g       *ABS*	00000000 __USER_SIGNATURE_REGION_LENGTH__
0080007f g     O .bss	00000002 usbMsgPtr
00007112  w      .text	00000000 __vector_15
00800081 g     O .bss	00000001 usbRxLen
000070c4 g       .text	00000000 __dtors_start
000070c4 g       .text	00000000 __ctors_end
0000085f  w      *ABS*	00000000 __stack
00800082 g     O .bss	00000001 usbNewDeviceAddr
00800066 g       .data	00000000 _edata
0080009d g       .noinit	00000000 _end
00007112  w      .text	00000000 __vector_8
00007854  w      .text	00000000 .hidden exit
00800083 g     O .bss	00000001 usbCurrentTok
00007096 g     O .text	0000000e usbDescriptorStringDevice
00010000 g       *ABS*	00000000 __EEPROM_REGION_LENGTH__
00007854 g       .text	00000000 .hidden _exit
00800084 g     O .bss	00000001 usbConfiguration
00007112  w      .text	00000000 __vector_14
00007112  w      .text	00000000 __vector_10
00800085 g     O .bss	00000016 usbRxBuf
00007112  w      .text	00000000 __vector_16
00800060 g       .data	00000000 __data_start
00007112  w      .text	00000000 __vector_18
00000400 g       *ABS*	00000000 __FUSE_REGION_LENGTH__
00020000 g       *ABS*	00000000 __TEXT_REGION_LENGTH__
00007112  w      .text	00000000 __vector_20



Disassembly of section .text:

00007000 <__vectors>:
    7000:	61 c0       	rjmp	.+194    	; 0x70c4 <__ctors_end>
    7002:	00 00       	nop
    7004:	a0 c0       	rjmp	.+320    	; 0x7146 <__vector_1>
    7006:	00 00       	nop
    7008:	84 c0       	rjmp	.+264    	; 0x7112 <__bad_interrupt>
    700a:	00 00       	nop
    700c:	82 c0       	rjmp	.+260    	; 0x7112 <__bad_interrupt>
    700e:	00 00       	nop
    7010:	80 c0       	rjmp	.+256    	; 0x7112 <__bad_interrupt>
    7012:	00 00       	nop
    7014:	7e c0       	rjmp	.+252    	; 0x7112 <__bad_interrupt>
    7016:	00 00       	nop
    7018:	7c c0       	rjmp	.+248    	; 0x7112 <__bad_interrupt>
    701a:	00 00       	nop
    701c:	7a c0       	rjmp	.+244    	; 0x7112 <__bad_interrupt>
    701e:	00 00       	nop
    7020:	78 c0       	rjmp	.+240    	; 0x7112 <__bad_interrupt>
    7022:	00 00       	nop
    7024:	76 c0       	rjmp	.+236    	; 0x7112 <__bad_interrupt>
    7026:	00 00       	nop
    7028:	74 c0       	rjmp	.+232    	; 0x7112 <__bad_interrupt>
    702a:	00 00       	nop
    702c:	72 c0       	rjmp	.+228    	; 0x7112 <__bad_interrupt>
    702e:	00 00       	nop
    7030:	70 c0       	rjmp	.+224    	; 0x7112 <__bad_interrupt>
    7032:	00 00       	nop
    7034:	6e c0       	rjmp	.+220    	; 0x7112 <__bad_interrupt>
    7036:	00 00       	nop
    7038:	6c c0       	rjmp	.+216    	; 0x7112 <__bad_interrupt>
    703a:	00 00       	nop
    703c:	6a c0       	rjmp	.+212    	; 0x7112 <__bad_interrupt>
    703e:	00 00       	nop
    7040:	68 c0       	rjmp	.+208    	; 0x7112 <__bad_interrupt>
    7042:	00 00       	nop
    7044:	66 c0       	rjmp	.+204    	; 0x7112 <__bad_interrupt>
    7046:	00 00       	nop
    7048:	64 c0       	rjmp	.+200    	; 0x7112 <__bad_interrupt>
    704a:	00 00       	nop
    704c:	62 c0       	rjmp	.+196    	; 0x7112 <__bad_interrupt>
    704e:	00 00       	nop
    7050:	60 c0       	rjmp	.+192    	; 0x7112 <__bad_interrupt>
	...

00007054 <bootloader__do_spm>:
    7054:	ec 2d fd 2d b7 b6 b0 fc fd cf 27 bf e8 95 b7 b6     .-.-......'.....
    7064:	b0 fc fd cf 21 e1 b7 b6 b6 fc f4 cf 08 95           ....!.........

00007072 <usbDescriptorConfiguration>:
    7072:	09 02 12 00 01 01 00 80 32 09 04 00 00 00 00 00     ........2.......
	...

00007084 <usbDescriptorDevice>:
    7084:	12 01 10 01 ff 00 00 08 c0 16 dc 05 02 01 01 02     ................
    7094:	00 01                                               ..

00007096 <usbDescriptorStringDevice>:
    7096:	0e 03 55 00 53 00 42 00 61 00 73 00 70 00           ..U.S.B.a.s.p.

000070a4 <usbDescriptorStringVendor>:
    70a4:	1c 03 77 00 77 00 77 00 2e 00 66 00 69 00 73 00     ..w.w.w...f.i.s.
    70b4:	63 00 68 00 6c 00 2e 00 64 00 65 00                 c.h.l...d.e.

000070c0 <usbDescriptorString0>:
    70c0:	04 03 09 04                                         ....

000070c4 <__ctors_end>:
    70c4:	11 24       	eor	r1, r1
    70c6:	1f be       	out	0x3f, r1	; 63
    70c8:	cf e5       	ldi	r28, 0x5F	; 95
    70ca:	d8 e0       	ldi	r29, 0x08	; 8
    70cc:	de bf       	out	0x3e, r29	; 62
    70ce:	cd bf       	out	0x3d, r28	; 61

000070d0 <__BOOTLOADERENTRY_FROMSOFTWARE__bootup_investigate_RAMEND>:
/* ------------------------------------------------------------------------ */

#if (HAVE_BOOTLOADERENTRY_FROMSOFTWARE)
void __attribute__ ((section(".init3"),naked,used,no_instrument_function)) __BOOTLOADERENTRY_FROMSOFTWARE__bootup_investigate_RAMEND(void);
void __BOOTLOADERENTRY_FROMSOFTWARE__bootup_investigate_RAMEND(void) {
  asm volatile (
    70d0:	24 b7       	in	r18, 0x34	; 52
    70d2:	d8 e0       	ldi	r29, 0x08	; 8
    70d4:	ce e5       	ldi	r28, 0x5E	; 94
    70d6:	39 91       	ld	r19, Y+
    70d8:	38 33       	cpi	r19, 0x38	; 56
    70da:	39 91       	ld	r19, Y+
    70dc:	09 f0       	breq	.+2      	; 0x70e0 <__BOOTLOADERENTRY_FROMSOFTWARE__bootup_investigate_RAMEND_done6>

000070de <__BOOTLOADERENTRY_FROMSOFTWARE__bootup_investigate_RAMEND_mismatch6>:
    70de:	3f ef       	ldi	r19, 0xFF	; 255

000070e0 <__BOOTLOADERENTRY_FROMSOFTWARE__bootup_investigate_RAMEND_done6>:
    70e0:	30 93 9c 00 	sts	0x009C, r19	; 0x80009c <__BOOTLOADERENTRY_FROMSOFTWARE__bootup_RAMEND_doesmatch>
    70e4:	20 93 9b 00 	sts	0x009B, r18	; 0x80009b <__bss_end>

000070e8 <__do_copy_data>:
    70e8:	10 e0       	ldi	r17, 0x00	; 0
    70ea:	a0 e6       	ldi	r26, 0x60	; 96
    70ec:	b0 e0       	ldi	r27, 0x00	; 0
    70ee:	e8 e5       	ldi	r30, 0x58	; 88
    70f0:	f8 e7       	ldi	r31, 0x78	; 120
    70f2:	02 c0       	rjmp	.+4      	; 0x70f8 <__do_copy_data+0x10>
    70f4:	05 90       	lpm	r0, Z+
    70f6:	0d 92       	st	X+, r0
    70f8:	a6 36       	cpi	r26, 0x66	; 102
    70fa:	b1 07       	cpc	r27, r17
    70fc:	d9 f7       	brne	.-10     	; 0x70f4 <__do_copy_data+0xc>

000070fe <__do_clear_bss>:
    70fe:	20 e0       	ldi	r18, 0x00	; 0
    7100:	a6 e6       	ldi	r26, 0x66	; 102
    7102:	b0 e0       	ldi	r27, 0x00	; 0
    7104:	01 c0       	rjmp	.+2      	; 0x7108 <.do_clear_bss_start>

00007106 <.do_clear_bss_loop>:
    7106:	1d 92       	st	X+, r1

00007108 <.do_clear_bss_start>:
    7108:	ab 39       	cpi	r26, 0x9B	; 155
    710a:	b2 07       	cpc	r27, r18
    710c:	e1 f7       	brne	.-8      	; 0x7106 <.do_clear_bss_loop>
    710e:	7e d1       	rcall	.+764    	; 0x740c <main>
    7110:	a1 c3       	rjmp	.+1858   	; 0x7854 <_exit>

00007112 <__bad_interrupt>:
    7112:	76 cf       	rjmp	.-276    	; 0x7000 <__vectors>

00007114 <usbCrc16>:
;   poly    r20+r21
;   scratch r23
;   resCrc  r24+r25 / r16+r17
;   ptr     X / Z
usbCrc16:
    mov     ptrL, argPtrL
    7114:	a8 2f       	mov	r26, r24
    mov     ptrH, argPtrH
    7116:	b9 2f       	mov	r27, r25
    ldi     resCrcL, 0
    7118:	80 e0       	ldi	r24, 0x00	; 0
    ldi     resCrcH, 0
    711a:	90 e0       	ldi	r25, 0x00	; 0
    ldi     polyL, lo8(0xa001)
    711c:	41 e0       	ldi	r20, 0x01	; 1
    ldi     polyH, hi8(0xa001)
    711e:	50 ea       	ldi	r21, 0xA0	; 160
    com     argLen      ; argLen = -argLen - 1: modified loop to ensure that carry is set
    7120:	60 95       	com	r22
    ldi     bitCnt, 0   ; loop counter with starnd condition = end condition
    7122:	30 e0       	ldi	r19, 0x00	; 0
    rjmp    usbCrcLoopEntry
    7124:	09 c0       	rjmp	.+18     	; 0x7138 <usbCrcLoopEntry>

00007126 <usbCrcByteLoop>:
usbCrcByteLoop:
    ld      byte, ptr+
    7126:	2d 91       	ld	r18, X+
    eor     resCrcL, byte
    7128:	82 27       	eor	r24, r18

0000712a <usbCrcBitLoop>:
usbCrcBitLoop:
    ror     resCrcH     ; carry is always set here (see brcs jumps to here)
    712a:	97 95       	ror	r25
    ror     resCrcL
    712c:	87 95       	ror	r24
    brcs    usbCrcNoXor
    712e:	10 f0       	brcs	.+4      	; 0x7134 <usbCrcNoXor>
    eor     resCrcL, polyL
    7130:	84 27       	eor	r24, r20
    eor     resCrcH, polyH
    7132:	95 27       	eor	r25, r21

00007134 <usbCrcNoXor>:
usbCrcNoXor:
    subi    bitCnt, 224 ; (8 * 224) % 256 = 0; this loop iterates 8 times
    7134:	30 5e       	subi	r19, 0xE0	; 224
    brcs    usbCrcBitLoop
    7136:	c8 f3       	brcs	.-14     	; 0x712a <usbCrcBitLoop>

00007138 <usbCrcLoopEntry>:
usbCrcLoopEntry:
    subi    argLen, -1
    7138:	6f 5f       	subi	r22, 0xFF	; 255
    brcs    usbCrcByteLoop
    713a:	a8 f3       	brcs	.-22     	; 0x7126 <usbCrcByteLoop>

0000713c <usbCrcReady>:
usbCrcReady:
    ret
    713c:	08 95       	ret

0000713e <usbCrc16Append>:

#endif /* USB_USE_FAST_CRC */

; extern unsigned usbCrc16Append(unsigned char *data, unsigned char len);
usbCrc16Append:
    rcall   usbCrc16
    713e:	ea df       	rcall	.-44     	; 0x7114 <usbCrc16>
    st      ptr+, resCrcL
    7140:	8d 93       	st	X+, r24
    st      ptr+, resCrcH
    7142:	9d 93       	st	X+, r25
    ret
    7144:	08 95       	ret

00007146 <__vector_1>:
; Numbers in brackets are clocks counted from center of last sync bit
; when instruction starts

USB_INTR_VECTOR:
;order of registers pushed: YL, SREG YH, [sofError], bitcnt, shift, x1, x2, x3, x4, cnt
    push    YL                  ;[-25] push only what is necessary to sync with edge ASAP
    7146:	cf 93       	push	r28
    in      YL, SREG            ;[-23]
    7148:	cf b7       	in	r28, 0x3f	; 63
    push    YL                  ;[-22]
    714a:	cf 93       	push	r28
    push    YH                  ;[-20]
    714c:	df 93       	push	r29

0000714e <waitForJ>:
;sync up with J to K edge during sync pattern -- use fastest possible loops
;The first part waits at most 1 bit long since we must be in sync pattern.
;YL is guarenteed to be < 0x80 because I flag is clear. When we jump to
;waitForJ, ensure that this prerequisite is met.
waitForJ:
    inc     YL
    714e:	c3 95       	inc	r28
    sbis    USBIN, USBMINUS
    7150:	83 9b       	sbis	0x10, 3	; 16
    brne    waitForJ        ; just make sure we have ANY timeout
    7152:	e9 f7       	brne	.-6      	; 0x714e <waitForJ>

00007154 <waitForK>:
waitForK:
;The following code results in a sampling window of < 1/4 bit which meets the spec.
    sbis    USBIN, USBMINUS     ;[-15]
    7154:	83 9b       	sbis	0x10, 3	; 16
    rjmp    foundK              ;[-14]
    7156:	0b c0       	rjmp	.+22     	; 0x716e <foundK>
    sbis    USBIN, USBMINUS
    7158:	83 9b       	sbis	0x10, 3	; 16
    rjmp    foundK
    715a:	09 c0       	rjmp	.+18     	; 0x716e <foundK>
    sbis    USBIN, USBMINUS
    715c:	83 9b       	sbis	0x10, 3	; 16
    rjmp    foundK
    715e:	07 c0       	rjmp	.+14     	; 0x716e <foundK>
    sbis    USBIN, USBMINUS
    7160:	83 9b       	sbis	0x10, 3	; 16
    rjmp    foundK
    7162:	05 c0       	rjmp	.+10     	; 0x716e <foundK>
    sbis    USBIN, USBMINUS
    7164:	83 9b       	sbis	0x10, 3	; 16
    rjmp    foundK
    7166:	03 c0       	rjmp	.+6      	; 0x716e <foundK>
    sbis    USBIN, USBMINUS
    7168:	83 9b       	sbis	0x10, 3	; 16
    rjmp    foundK
    716a:	01 c0       	rjmp	.+2      	; 0x716e <foundK>
    sts     usbSofCount, YL
#endif  /* USB_COUNT_SOF */
#ifdef USB_SOF_HOOK
    USB_SOF_HOOK
#endif
    rjmp    sofError
    716c:	89 c0       	rjmp	.+274    	; 0x7280 <sofError>

0000716e <foundK>:
foundK:                         ;[-12]
;{3, 5} after falling D- edge, average delay: 4 cycles [we want 5 for center sampling]
;we have 1 bit time for setup purposes, then sample again. Numbers in brackets
;are cycles from center of first sync (double K) bit after the instruction
    push    bitcnt              ;[-12]
    716e:	6f 93       	push	r22
;   [---]                       ;[-11]
    lds     YL, usbInputBufOffset;[-10]
    7170:	c0 91 7e 00 	lds	r28, 0x007E	; 0x80007e <usbInputBufOffset>
;   [---]                       ;[-9]
    clr     YH                  ;[-8]
    7174:	dd 27       	eor	r29, r29
    subi    YL, lo8(-(usbRxBuf));[-7] [rx loop init]
    7176:	cb 57       	subi	r28, 0x7B	; 123
    sbci    YH, hi8(-(usbRxBuf));[-6] [rx loop init]
    7178:	df 4f       	sbci	r29, 0xFF	; 255
    push    shift               ;[-5]
    717a:	2f 93       	push	r18
;   [---]                       ;[-4]
    ldi     bitcnt, 0x55        ;[-3] [rx loop init]
    717c:	65 e5       	ldi	r22, 0x55	; 85
    sbis    USBIN, USBMINUS     ;[-2] we want two bits K (sample 2 cycles too early)
    717e:	83 9b       	sbis	0x10, 3	; 16
    rjmp    haveTwoBitsK        ;[-1]
    7180:	03 c0       	rjmp	.+6      	; 0x7188 <haveTwoBitsK>
    pop     shift               ;[0] undo the push from before
    7182:	2f 91       	pop	r18
    pop     bitcnt              ;[2] undo the push from before
    7184:	6f 91       	pop	r22
    rjmp    waitForK            ;[4] this was not the end of sync, retry
    7186:	e6 cf       	rjmp	.-52     	; 0x7154 <waitForK>

00007188 <haveTwoBitsK>:

;----------------------------------------------------------------------------
; push more registers and initialize values while we sample the first bits:
;----------------------------------------------------------------------------
haveTwoBitsK:
    push    x1              ;[1]
    7188:	0f 93       	push	r16
    push    x2              ;[3]
    718a:	1f 93       	push	r17
    push    x3              ;[5]
    718c:	4f 93       	push	r20
    ldi     shift, 0        ;[7]
    718e:	20 e0       	ldi	r18, 0x00	; 0
    ldi     x3, 1<<4        ;[8] [rx loop init] first sample is inverse bit, compensate that
    7190:	40 e1       	ldi	r20, 0x10	; 16
    push    x4              ;[9] == leap
    7192:	5f 93       	push	r21

    in      x1, USBIN       ;[11] <-- sample bit 0
    7194:	00 b3       	in	r16, 0x10	; 16
    andi    x1, USBMASK     ;[12]
    7196:	0c 70       	andi	r16, 0x0C	; 12
    bst     x1, USBMINUS    ;[13]
    7198:	03 fb       	bst	r16, 3
    bld     shift, 7        ;[14]
    719a:	27 f9       	bld	r18, 7
    push    cnt             ;[15]
    719c:	3f 93       	push	r19
    ldi     leap, 0         ;[17] [rx loop init]
    719e:	50 e0       	ldi	r21, 0x00	; 0
    ldi     cnt, USB_BUFSIZE;[18] [rx loop init]
    71a0:	3b e0       	ldi	r19, 0x0B	; 11
    rjmp    rxbit1          ;[19] arrives at [21]
    71a2:	39 c0       	rjmp	.+114    	; 0x7216 <rxbit1>

000071a4 <unstuff6>:

; duration of unstuffing code should be 10.66666667 cycles. We adjust "leap"
; accordingly to approximate this value in the long run.

unstuff6:
    andi    x2, USBMASK ;[03]
    71a4:	1c 70       	andi	r17, 0x0C	; 12
    ori     x3, 1<<6    ;[04] will not be shifted any more
    71a6:	40 64       	ori	r20, 0x40	; 64
    andi    shift, ~0x80;[05]
    71a8:	2f 77       	andi	r18, 0x7F	; 127
    mov     x1, x2      ;[06] sampled bit 7 is actually re-sampled bit 6
    71aa:	01 2f       	mov	r16, r17
    subi    leap, -1    ;[07] total duration = 11 bits -> subtract 1/3
    71ac:	5f 5f       	subi	r21, 0xFF	; 255
    rjmp    didUnstuff6 ;[08]
    71ae:	1e c0       	rjmp	.+60     	; 0x71ec <didUnstuff6>

000071b0 <unstuff7>:
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

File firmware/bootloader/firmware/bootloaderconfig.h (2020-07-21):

/* Name: bootloaderconfig.h
 * Project: USBaspLoader
 * Author: Christian Starkjohann
 * Author: Stephan Baerwolf
 * Creation Date: 2007-12-08
 * Modification Date: 2013-03-31
 * Tabsize: 4
 * Copyright: (c) 2007 by OBJECTIVE DEVELOPMENT Software GmbH
 * License: GNU GPL v2 (see License.txt)
 */

#ifndef __bootloaderconfig_h_included__
#define __bootloaderconfig_h_included__
#include "../misc/iofixes.h"

/*
General Description:
This file (together with some settings in Makefile) configures the boot loader
according to the hardware.

This file contains (besides the hardware configuration normally found in
usbconfig.h) two functions or macros: bootLoaderInit() and
bootLoaderCondition(). Whether you implement them as macros or as static
inline functions is up to you, decide based on code size and convenience.

bootLoaderInit() is called as one of the first actions after reset. It should
be a minimum initialization of the hardware so that the boot loader condition
can be read. This will usually consist of activating a pull-up resistor for an
external jumper which selects boot loader mode.

bootLoaderCondition() is called immediately after initialization and in each
main loop iteration. If it returns TRUE, the boot loader will be active. If it
returns FALSE, the boot loader jumps to address 0 (the loaded application)
immediately.

For compatibility with Thomas Fischl's avrusbboot, we also support the macro
names BOOTLOADER_INIT and BOOTLOADER_CONDITION for this functionality. If
these macros are defined, the boot loader usees them.
*/

/* ---------------------------- Macro Magic ---------------------------- */
#define		PIN_CONCAT(a,b)			a ## b
#define		PIN_CONCAT3(a,b,c)		a ## b ## c

#define		PIN_PORT(a)			PIN_CONCAT(PORT, a)
#define		PIN_PIN(a)			PIN_CONCAT(PIN, a)
#define		PIN_DDR(a)			PIN_CONCAT(DDR, a)

#define		PIN(a, b)			PIN_CONCAT3(P, a, b)

/* ---------------------------- Hardware Config ---------------------------- */

#ifndef USB_CFG_IOPORTNAME
  #define USB_CFG_IOPORTNAME      D
#endif
/* This is the port where the USB bus is connected. When you configure it to
 * "B", the registers PORTB, PINB and DDRB will be used.
 */
#ifndef USB_CFG_INTPORT_BIT
  #if (defined(__AVR_ATmega640__) || defined (__AVR_ATmega128__) || defined(__AVR_ATmega1280__) || defined(__AVR_ATmega1281__) || defined(__AVR_ATmega2560__) || defined(__AVR_ATmega2561__))
    #define USB_CFG_INTPORT_BIT 0
  #else
    #define USB_CFG_INTPORT_BIT 2
  #endif
#endif
/* Not all devices have their INT0 on PD2.
 * Since "INT0" and "USB_CFG_DPLUS_BIT" should get the same signals,
 * map them to be ideally the same:
 * So abstract "USB_CFG_DPLUS_BIT" to this one here.
 */

#ifndef USB_CFG_DMINUS_BIT
  /* This is Revision 3 and later (where PD6 and PD7 were swapped */
  // #define USB_CFG_DMINUS_BIT      7    /* Rev.2 and previous was 6 */
  #define USB_CFG_DMINUS_BIT  3
#endif
/* This is the bit number in USB_CFG_IOPORT where the USB D- line is connected.
 * This may be any bit in the port.
 */
#ifndef USB_CFG_DPLUS_BIT
  #define USB_CFG_DPLUS_BIT       USB_CFG_INTPORT_BIT
#endif
/* This is the bit number in USB_CFG_IOPORT where the USB D+ line is connected.
 * This may be any bit in the port. Please note that D+ must also be connected
 * to interrupt pin INT0!
 */
#ifndef JUMPER_PORT
  #define JUMPER_PORT		USB_CFG_IOPORTNAME
#endif
/* 
 * jumper is connected to this port
 */
#ifndef JUMPER_BIT
  /* This is Revision 3 and later (where PD6 and PD7 were swapped */
  // #define JUMPER_BIT           7       /* Rev.2 and previous was 7 */
  #define JUMPER_BIT           4
#endif
/* 
 * jumper is connected to this bit in port "JUMPER_PORT", active low
 */
#define USB_CFG_CLOCK_KHZ       (F_CPU/1000)
/* Clock rate of the AVR in MHz. Legal values are 12000, 16000 or 16500.
 * The 16.5 MHz version of the code requires no crystal, it tolerates +/- 1%
 * deviation from the nominal frequency. All other rates require a precision
 * of 2000 ppm and thus a crystal!
 * Default if not specified: 12 MHz
 */

/* ----------------------- Optional Hardware Config ------------------------ */

/* #define USB_CFG_PULLUP_IOPORTNAME   D */
/* If you connect the 1.5k pullup resistor from D- to a port pin instead of
 * V+, you can connect and disconnect the device from firmware by calling
 * the macros usbDeviceConnect() and usbDeviceDisconnect() (see usbdrv.h).
 * This constant defines the port on which the pullup resistor is connected.
 */
/* #define USB_CFG_PULLUP_BIT          4 */
/* This constant defines the bit number in USB_CFG_PULLUP_IOPORT (defined
 * above) where the 1.5k pullup resistor is connected. See description
 * above for details.
 */

/* ------------------------------------------------------------------------- */
/* ---------------------- feature / code size options ---------------------- */
/* ------------------------------------------------------------------------- */
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

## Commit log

2020-07-21 fix layout and add firmware
    [sesame.kicad_pcb]
2020-07-22 fix diode placement
    [sesame.kicad_pcb]
2020-07-27 added extras and qmk info.json
    [backplate.kicad_pcb, switchplate.kicad_pcb]
2020-07-30 fix ground plane
    [sesame.kicad_pcb]
2020-07-30 update switchplate
    [switchplate.kicad_pcb]
2020-07-30 add teardrops
    [sesame.kicad_pcb]
2020-08-02 update plate and add feet to bottom
    [backplate.kicad_pcb, switchplate.kicad_pcb]
2020-08-02 add stepped caps support
    [sesame.kicad_pcb, sesame.sch]
2020-08-10 minor design changes
    [backplate.gbl, backplate.gbo, backplate.gbp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]
2020-08-30 fix routing error
    [backplate-B_Cu.gbr, backplate-B_Mask.gbr, backplate-B_SilkS.gbr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]
2020-10-02 remove wrong case files
    [sesame.f3d]
2020-10-18 fix screwhole position on backplate
    [backplate-B_Cu.gbr, backplate-B_Mask.gbr, backplate-B_SilkS.gbr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]
2021-01-16 add acrylic layer case
    [feet.dxf, sheet-bottom.dxf, sheet-frame-bottom-usb.dxf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]
2021-01-16 update case
    [layer-bottom.dxf, layer-feet-big.dxf, layer-feet-small.dxf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]
2021-01-16 update case (again)
    [layer-feet-big.dxf, layer-feet-small.dxf, layer-frame-bottom-usb.dxf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]
2021-01-18 update gerbers to latest kicad version defaults
    [backplate-B_Cu.gbr, backplate-B_Mask.gbr, backplate-B_SilkS.gbr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]
2021-02-03 update acrylic case
    [layer-feet-big.dxf, layer-feet-bottom.dxf, layer-feet-small.dxf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]
2021-02-20 fix top frame
    [layer-frame-top.dxf, layer-top.dxf]
2021-02-22 update gerbers
    [backplate-B_Cu.gbr, backplate-B_Mask.gbr, backplate-B_SilkS.gbr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]
2021-04-17 add 2.25u left space support and update caps to use cftkb footprints
    [sesame-B_Cu.gbr, sesame-B_Mask.gbr, sesame-B_SilkS.gbr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]
2021-04-17 fix silkscreen
    [sesame-B_Cu.gbr, sesame-B_Mask.gbr, sesame-B_SilkS.gbr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]
2021-04-17 fix silkscreen (again)
    [sesame-B_Cu.gbr, sesame-B_Mask.gbr, sesame-B_SilkS.gbr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]
2021-12-09 change fuse LCSC part

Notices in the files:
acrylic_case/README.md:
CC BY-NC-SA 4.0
